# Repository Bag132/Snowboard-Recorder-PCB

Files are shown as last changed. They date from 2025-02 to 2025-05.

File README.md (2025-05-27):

# Snowboard-Recorder-PCB
## Purpose
I designed this board for a Software Engineering class project. The PCB was made to facilitate communication between a ESP32-WROVER SoC and BNO086 IMU which the ESP32 then reports constant updates to a mobile app through Bluetooth. In practice, the PCB is installed into a housing which is then mounted on a snowboard.
## Remarks
I2C should not have been used to communicate with the BNO086 because the updated ESP32 I2C driver does not support SCL-stretching, which the BNO086 needs to communicate without issues arising. Only the legacy ESP-IDF driver consisitently works with it. SPI should have been used in place of I2C.
## Pictures
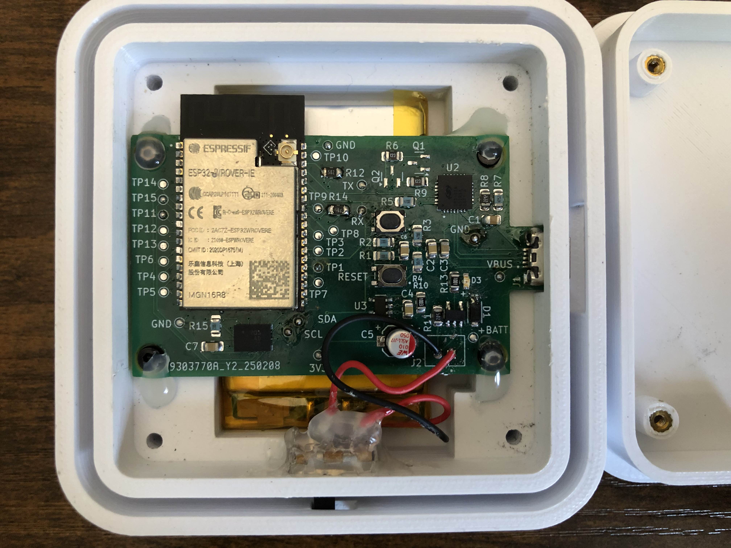
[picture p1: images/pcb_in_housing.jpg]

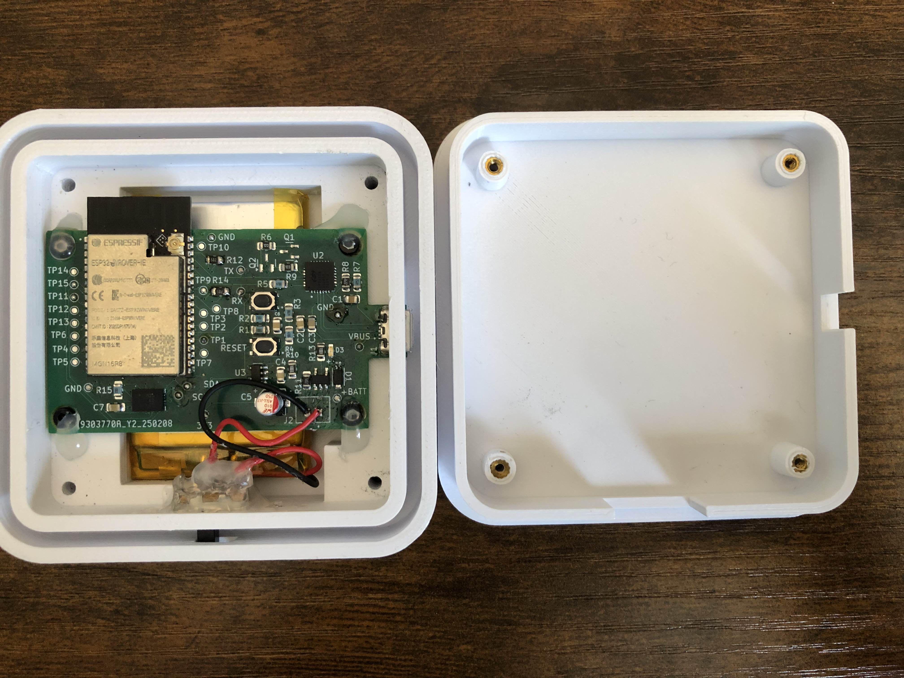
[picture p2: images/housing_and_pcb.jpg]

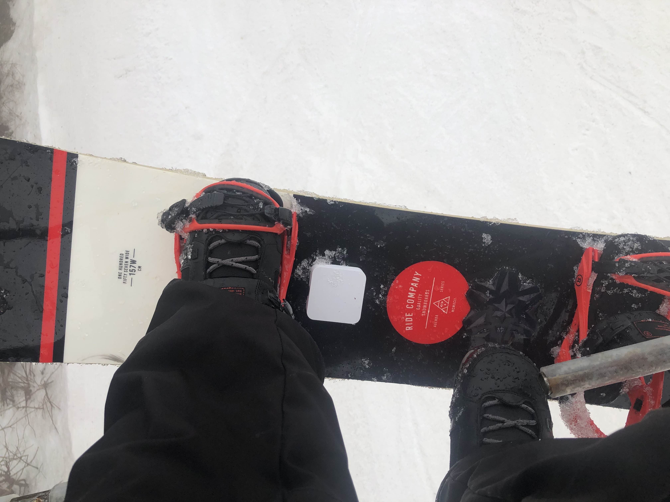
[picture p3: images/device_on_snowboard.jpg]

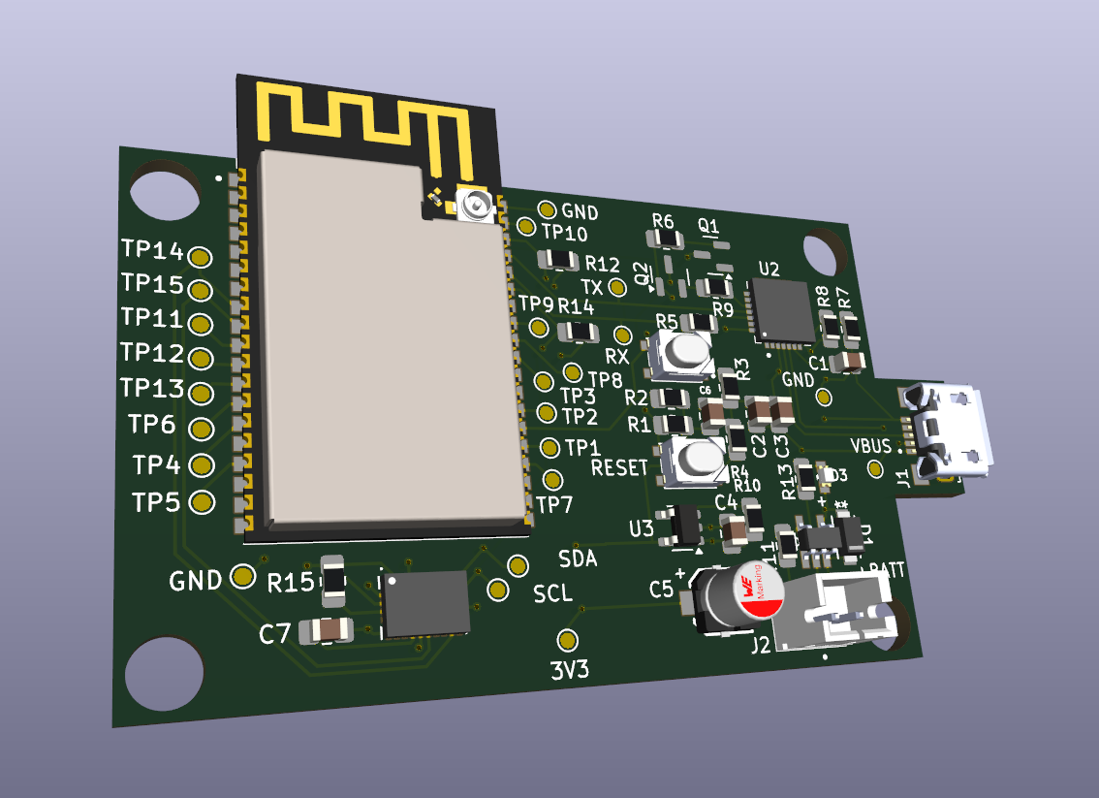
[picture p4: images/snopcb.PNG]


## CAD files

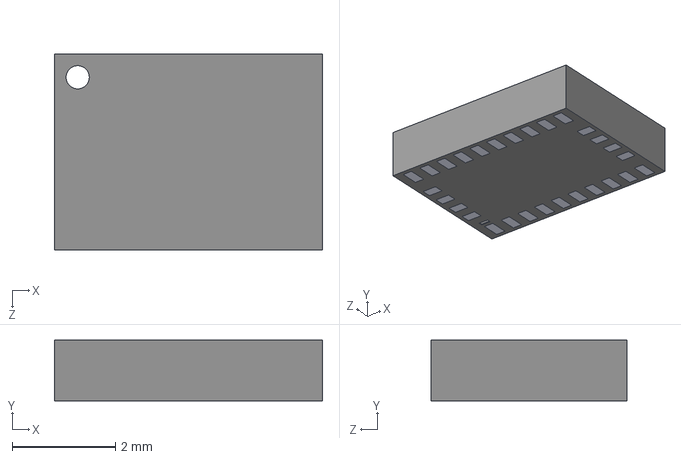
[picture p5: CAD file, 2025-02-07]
models/BNO080.step
5.20 x 1.18 x 3.80 mm

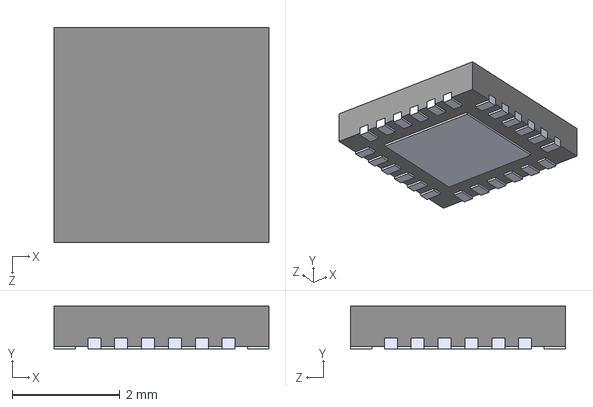
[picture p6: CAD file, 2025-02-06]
models/CP2102N-A02-GQFN24.step
4.00 x 0.8 x 4.00 mm

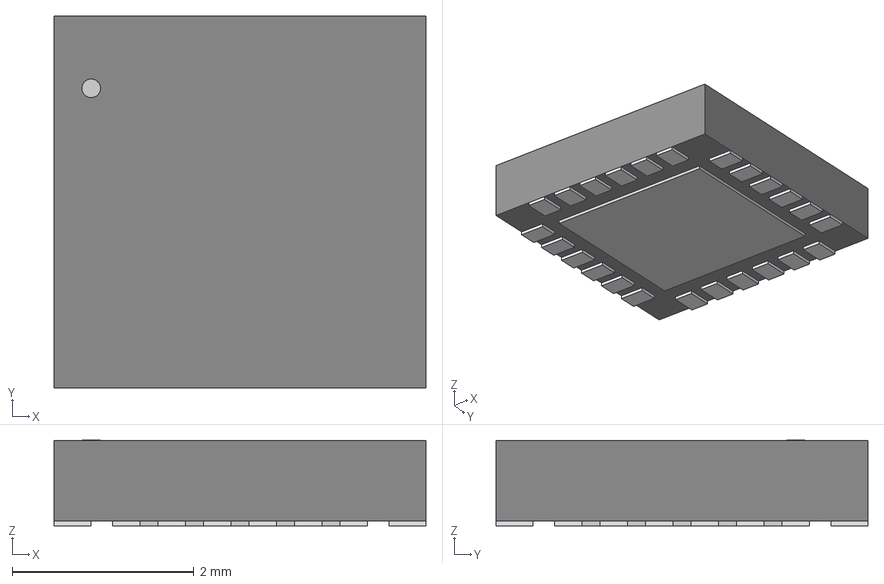
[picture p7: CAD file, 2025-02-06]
models/MPU6050_QFN24_4X4X0P9-0P5_TDK.step
4.09 x 4.09 x 0.942 mm

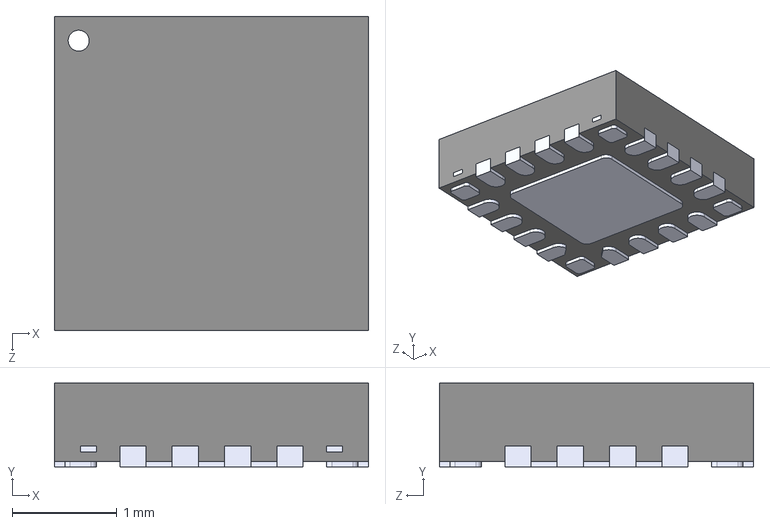
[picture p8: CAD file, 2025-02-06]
models/CP2102N-A02-GQFN20R.step
3.00 x 0.8 x 3.00 mm

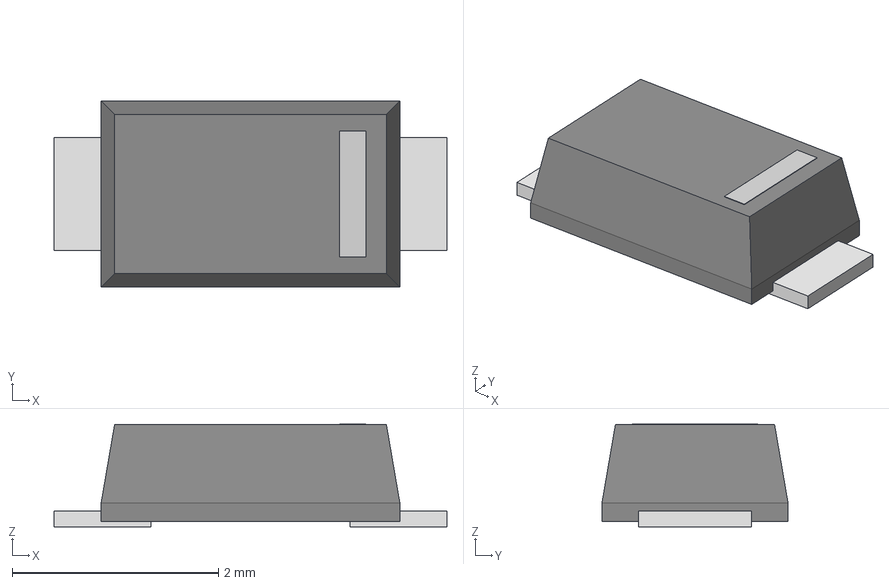
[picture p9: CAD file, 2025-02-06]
models/SDO_SOD-123FL_498__OSI.step
3.81 x 1.80 x 0.997 mm

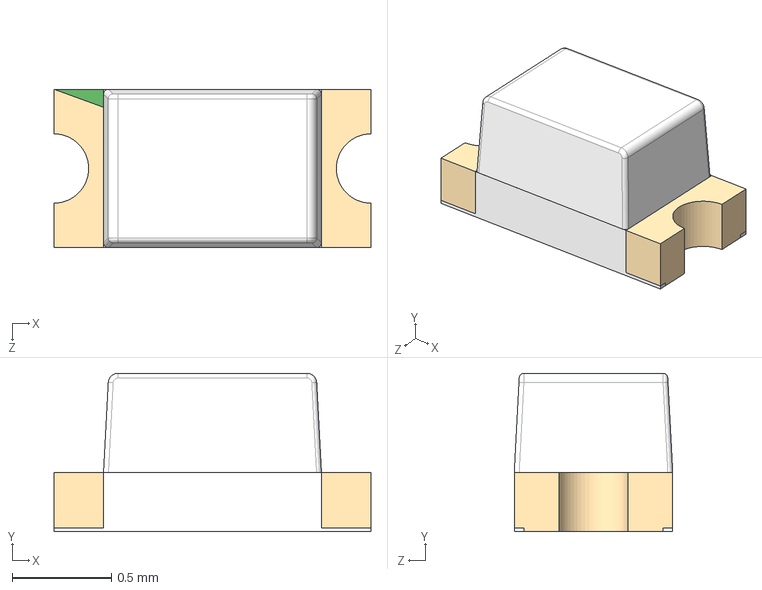
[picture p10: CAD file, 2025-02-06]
models/WL-SMCW_0603.step
1.60 x 0.8 x 0.8 mm

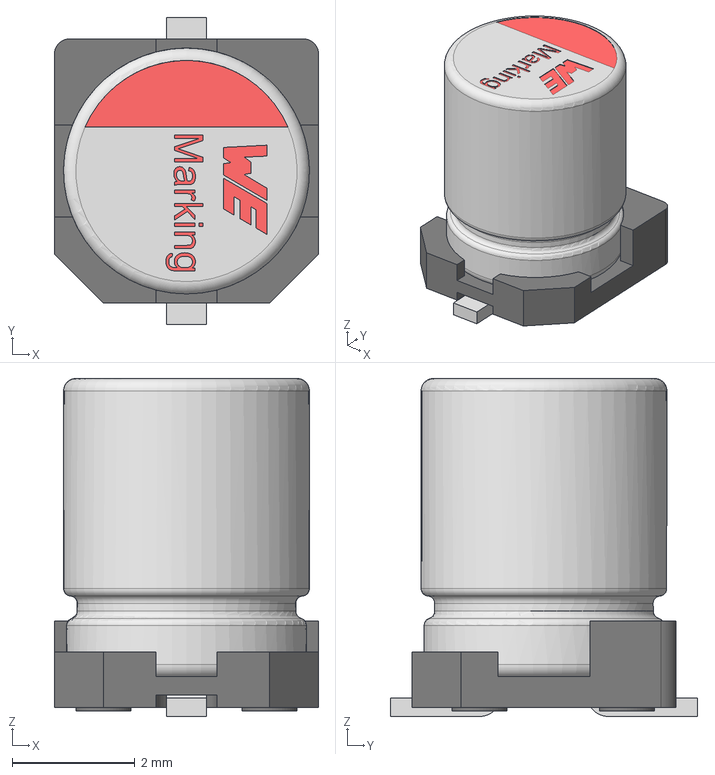
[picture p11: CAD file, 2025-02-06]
models/WCAP-ASLL_4X5.5.step
4.30 x 5.00 x 5.50 mm
capicitor_4x5.5x1
Base_Φ4Capacitor

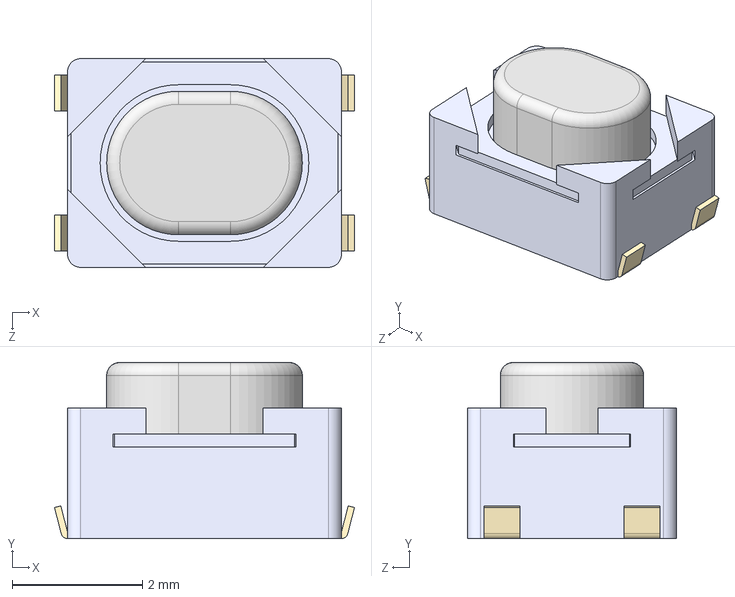
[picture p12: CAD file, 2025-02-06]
models/PTS810_SJM_250_SMTR_LFS.step
4.60 x 2.70 x 3.20 mm

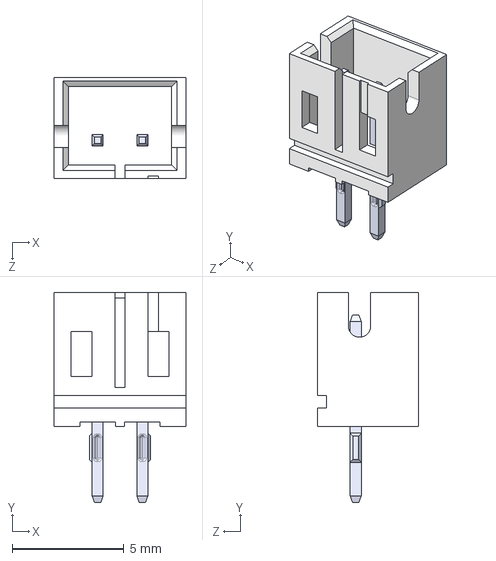
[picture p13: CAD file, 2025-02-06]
models/B2B-PH-K-S.step
5.90 x 9.40 x 4.50 mm

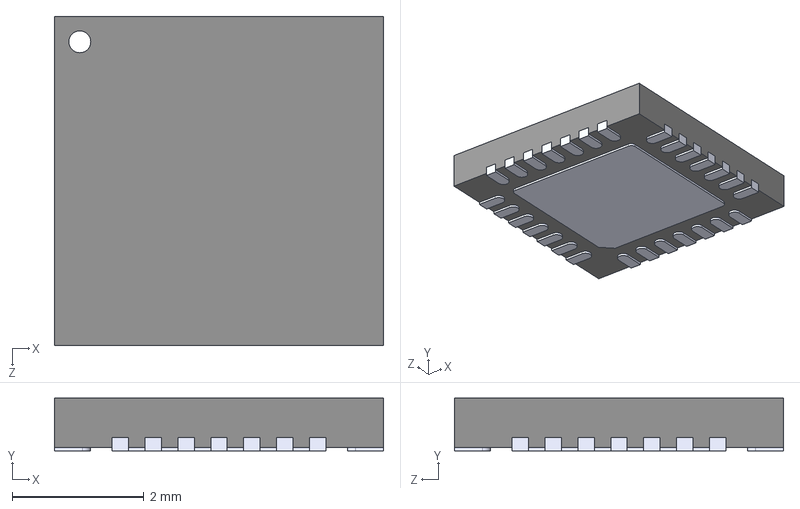
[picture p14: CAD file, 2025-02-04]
models/CP2102N-A02-GQFN28R.step
5.00 x 0.8 x 5.00 mm

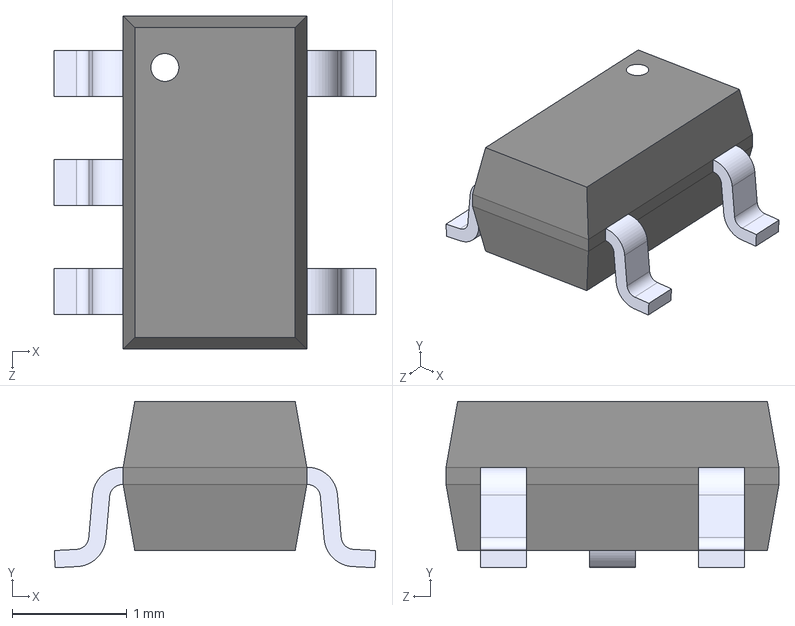
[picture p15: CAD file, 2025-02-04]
models/SPX3819M5-L-3-3.step
2.80 x 1.45 x 2.90 mm

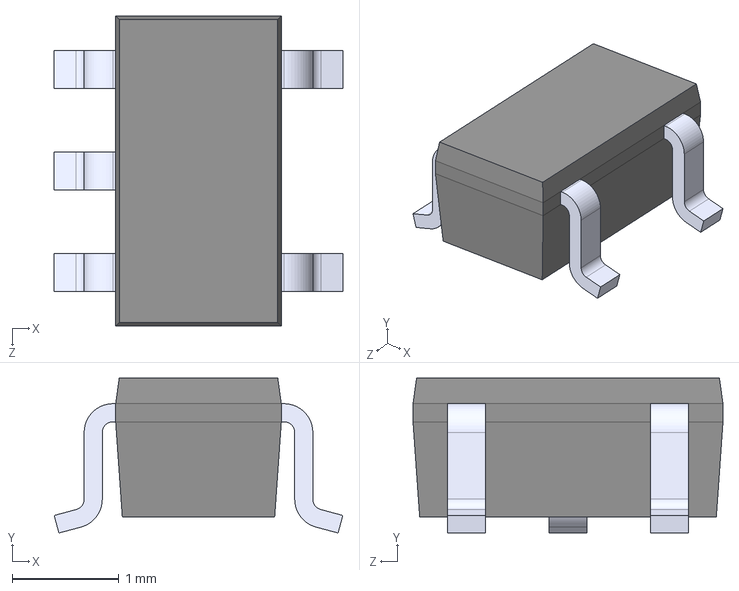
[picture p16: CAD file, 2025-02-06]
models/MCP73831T-2ACI_OT.step
2.70 x 1.45 x 2.90 mm

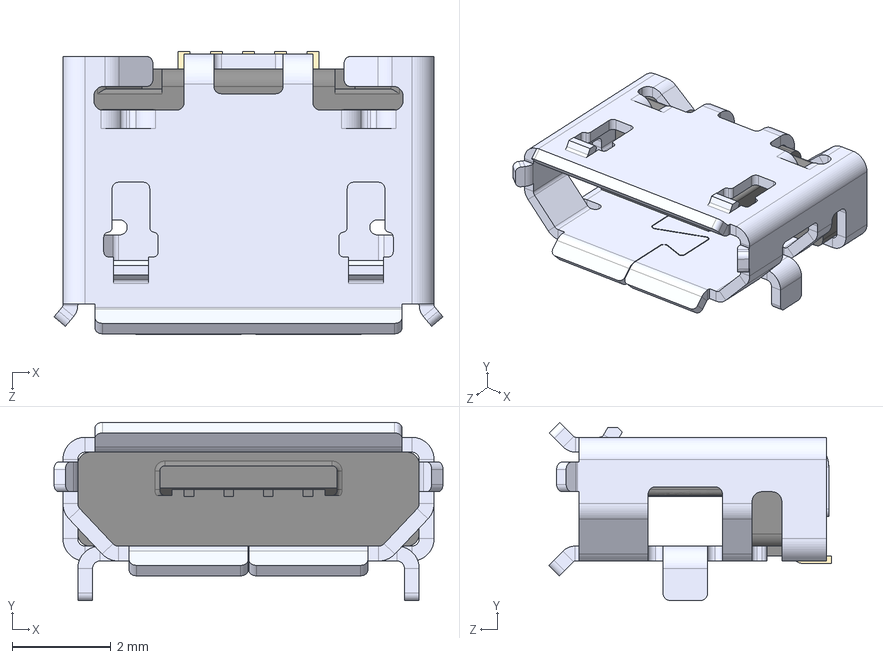
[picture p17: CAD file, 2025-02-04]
models/10118193-0001LF.step
7.86 x 3.60 x 5.71 mm

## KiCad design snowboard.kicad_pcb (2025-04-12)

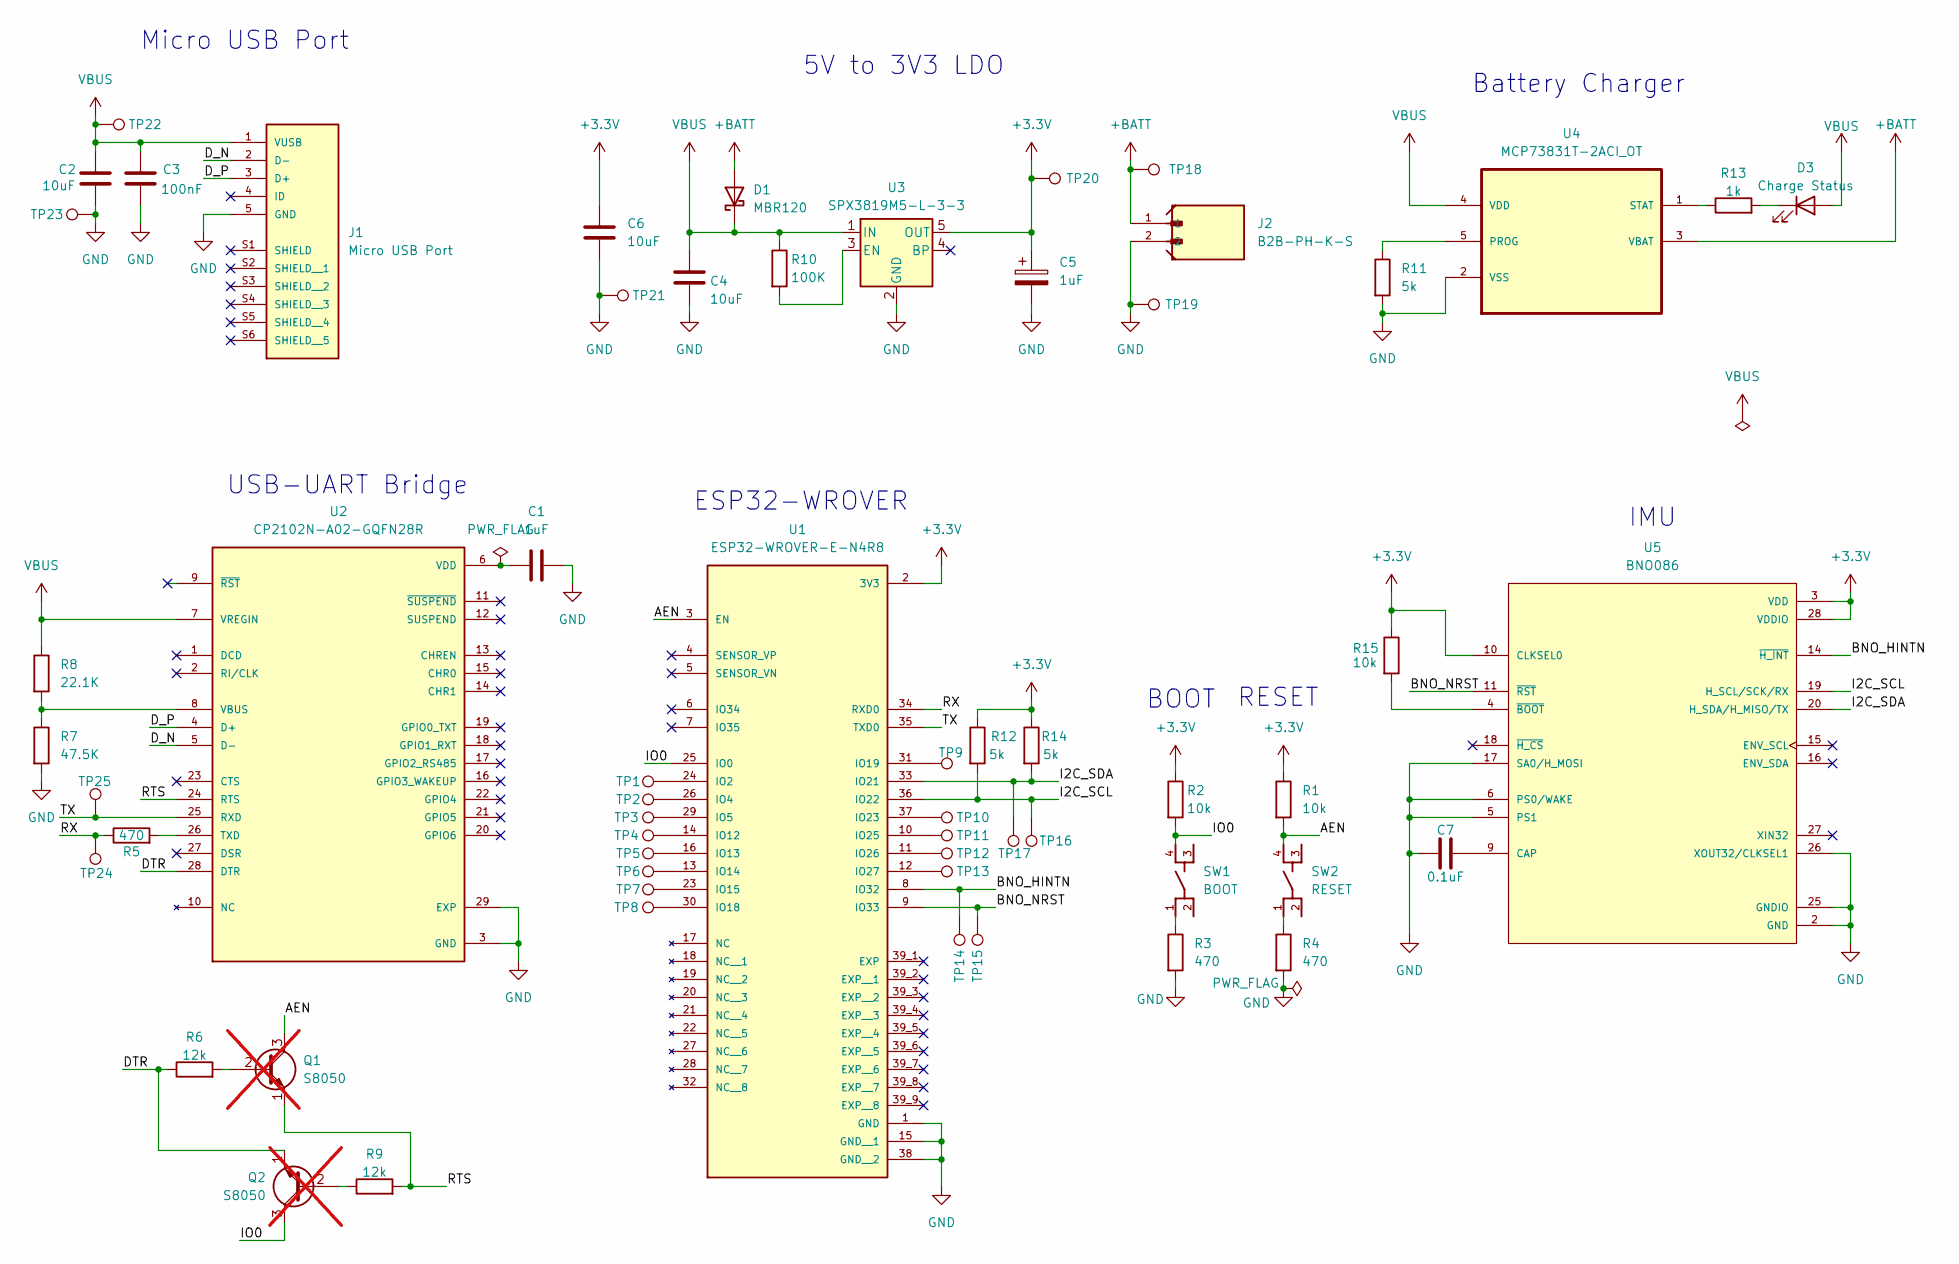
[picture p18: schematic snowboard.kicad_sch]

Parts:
C1, C5: 1uF
C2, C4, C6: 10uF
C3: 100nF
C7: 0.1uF
D1: MBR120
D3: Charge Status
J1: Micro USB Port; AMPHENOL_10118193-0001LF; PARTREV E
J2: B2B-PH-K-S; JST_B2B-PH-K-S
Q1, Q2: S8050; TO-92_Inline; not fitted
R1, R2, R15: 10k
R3, R4, R5: 470
R6, R9: 12k
R7: 47.5K
R8: 22.1K
R10: 100K
R11, R12, R14: 5k
R13: 1k
SW1: BOOT; SW_PTS810_SJM_250_SMTR_LFS
SW2: RESET; SW_PTS810_SJM_250_SMTR_LFS
TP1, TP2, TP3, TP4, TP5, TP6, TP7, TP8, TP9, TP10, TP11, TP12, TP13, TP14, TP15, TP16, TP17, TP18, TP19, TP20, TP21, TP22, TP23, TP24, TP25: TestPoint
U1: ESP32-WROVER-E-N4R8; XCVR_ESP32-WROVER-E-N4R8; PARTREV 1.6
U2: CP2102N-A02-GQFN28R; IC_CP2102N-A02-GQFN28R; PARTREV 1.5
U3: SPX3819M5-L-3-3; SOT-23-5
U4: MCP73831T-2ACI_OT; SOT95P280X145-5N; MPN MCP73831T-2ACI/OT
U5: BNO086; IC_BNO080; PARTREV 1.6

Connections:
+3.3V: C5.1, C6.1, R1.1, R2.1, R12.1, R14.1, R15.1, TP20.1, U1.2 (3V3), U3.5 (OUT), U5.3 (VDD), U5.10 (CLKSEL0), U5.28 (VDDIO)
+BATT: D1.2 (A), J2.1, TP18.1, U4.3 (VBAT)
/AEN: Q1.3 (C), R1.2, SW2.4, U1.3 (EN)
/BNO_HINTN: TP14.1, U1.8 (IO32), U5.14 (~H_INT)
/BNO_NRST: TP15.1, U1.9 (IO33), U5.11 (~RST)
/DTR: Q2.1 (E), R6.1, U2.28 (DTR)
/D_N: J1.2 (D-), U2.5 (D-)
/D_P: J1.3 (D+), U2.4 (D+)
/I2C_SCL: R12.2, TP16.1, U1.36 (IO22), U5.19 (H_SCL/SCK/RX)
/I2C_SDA: R14.2, TP17.1, U1.33 (IO21), U5.20 (H_SDA/H_MISO/TX)
/IO0: Q2.3 (C), R2.2, SW1.4, U1.25 (IO0)
/RTS: Q1.1 (E), R9.2, U2.24 (RTS)
/RX: R5.1, TP24.1, U1.34 (RXD0)
/TX: TP25.1, U1.35 (TXD0), U2.25 (RXD)
GND: C1.2, C2.2, C3.2, C4.2, C5.2, C6.2, C7.1, J1.5 (GND), J2.2, R3.2, R4.2, R7.2, R11.2, TP19.1, TP21.1, TP23.1, U1.1 (GND), U1.15 (GND__1), U1.38 (GND__2), U2.3 (GND), U2.29 (EXP), U3.2 (GND), U4.2 (VSS), U5.2 (GND), U5.5 (PS1), U5.6 (PS0/WAKE), U5.17 (SA0/H_MOSI), U5.25 (GNDIO), U5.26 (XOUT32/CLKSEL1)
unnamed: D3.1 (K), R13.2
unnamed: Q1.2 (B), R6.2
unnamed: Q2.2 (B), R9.1
unnamed: R3.1, SW1.1
unnamed: R4.1, SW2.1
unnamed: TP1.1, U1.24 (IO2)
unnamed: TP2.1, U1.26 (IO4)
unnamed: TP3.1, U1.29 (IO5)
unnamed: TP4.1, U1.14 (IO12)
unnamed: TP5.1, U1.16 (IO13)
unnamed: TP6.1, U1.13 (IO14)
unnamed: TP7.1, U1.23 (IO15)
unnamed: TP8.1, U1.30 (IO18)
unnamed: TP9.1, U1.31 (IO19)
unnamed: TP10.1, U1.37 (IO23)
unnamed: TP11.1, U1.10 (IO25)
unnamed: TP12.1, U1.11 (IO26)
unnamed: TP13.1, U1.12 (IO27)
unnamed: R5.2, U2.26 (TXD)
unnamed: R7.1, R8.2, U2.8 (VBUS)
unnamed: C1.1, U2.6 (VDD)
unnamed: R10.2, U3.3 (EN)
unnamed: R11.1, U4.5 (PROG)
unnamed: R13.1, U4.1 (STAT)
unnamed: C7.2, U5.9 (CAP)
unnamed: R15.2, U5.4 (~BOOT)
VBUS: C2.1, C3.1, C4.1, D1.1 (K), D3.2 (A), J1.1 (VUSB), R8.1, R10.1, TP22.1, U2.7 (VREGIN), U3.1 (IN), U4.4 (VDD)

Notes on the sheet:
USB-UART Bridge
IMU
Battery Charger
Micro USB Port
ESP32-WROVER
RESET
5V to 3V3 LDO
BOOT

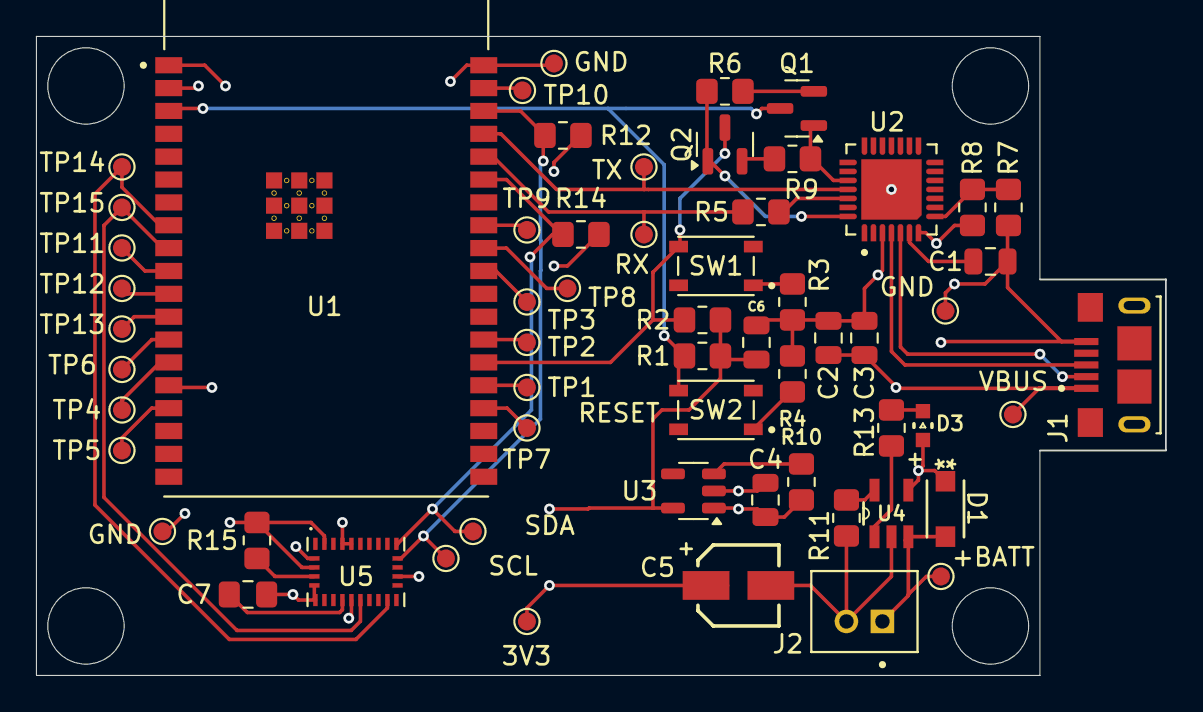
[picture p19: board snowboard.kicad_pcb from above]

Board: 4 copper layers, 62.8 x 35.5 mm, 60 parts (0 on the bottom side), 42 nets.

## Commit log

2025-02-04 Base ESP Schematic
    [10118193-0001LF.step, CP2102N-A02-GQFN28R.step, SPX3819M5-L-3-3.step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]
2025-02-06 Started PCB
    [B2B-PH-K-S.step, MCP73831T-2ACI_OT.step, PTS810_SJM_250_SMTR_LFS.step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]
2025-02-06 Update battery connector
    [snowboard.kicad_pcb, snowboard.kicad_sch]
2025-02-06 Add footprints and models and place components on PCB
    [SDO_SOD-123FL_498__OSI.step, WCAP-ASLL_4X5.5.step, WL-SMCW_0603.step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]
2025-02-06 PCB routing mostly done
    [CP2102N-A02-GQFN20R.step, CP2102N-A02-GQFN24.step, MPU6050_QFN24_4X4X0P9-0P5_TDK.step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]
2025-02-06 Add IMU
    [snowboard.kicad_pcb, snowboard.kicad_sch]
2025-02-06 Add test points
    [snowboard.kicad_pcb, snowboard.kicad_sch]
2025-02-07 Swap discontinued MPU6050 for BNO086
    [BNO080.step, snowboard.kicad_pcb, snowboard.kicad_sch]
2025-02-07 Fix track spacing
    [snowboard-B_Cu.gbr, snowboard-B_Mask.gbr, snowboard-B_Paste.gbr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]
2025-04-12 Reduce i2c pull-up value, fix shorting LDO, DNP auto-reset
    [snowboard.kicad_pcb, snowboard.kicad_sch]
